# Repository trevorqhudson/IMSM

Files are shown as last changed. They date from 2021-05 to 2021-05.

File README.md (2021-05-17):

# IMSM
integrated multi-sensor module (IMSM) for transducing flow dynamics in hydrocephalic shunts

This repo contains firmware + schematics for a portable datalogger designed for an prototype polymer sensor device.

### Features: ###
* IMSM thermal flow sensor, bubble pressure sensor, and substrate/electrode integrity sensors using AD5933 LCR IC
* Low-side current sensing thru flow sensor heater 
* Sensirion LD20 flow sensor (I2C)
* EIS/CV sweeps addressable to any of 4 measurement electrode pairs + electrolysis electrodes
* Extends frequency range of AD5933 both low and high w/ external clock (code incomplete, but tapeout done)
* Completely autonomous data collection - designed for clinician use, not for researchers only
* Low-power + sleep mode extends battery life

[Meng Lab research page](https://biomems.usc.edu/ "easter egg text")

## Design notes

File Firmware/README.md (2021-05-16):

# Readme
Arduino code to interface AD5933 impedance analyzer and Teensy 3.2 microcontroller.
Used for flow and pressure sensing in platinum/Parylene C thin-film device.

Features:
* IMSM thermal flow sensor, bubble pressure sensor, and substrate/electrode integrity sensors using AD5933 LCR IC
* Low-side current sensing thru flow sensor heater 
* Sensirion LD20 flow sensor (I2C)
* EIS/CV sweeps addressable to any of 4 measurement electrode pairs + electrolysis electrodes
* Extends frequency range of AD5933 both low and high w/ external clock (code incomplete, but tapeout done)
* Completely autonomous data collection - designed for clinician use, not for engineers
* Low-power + sleep mode extends battery life

### Libraries ###
* Wire.h
* SD.h
* SPI.h
* math.h
* Time.h
* TimeLib.h
* Snooze.h
* SnoozeBlock.h

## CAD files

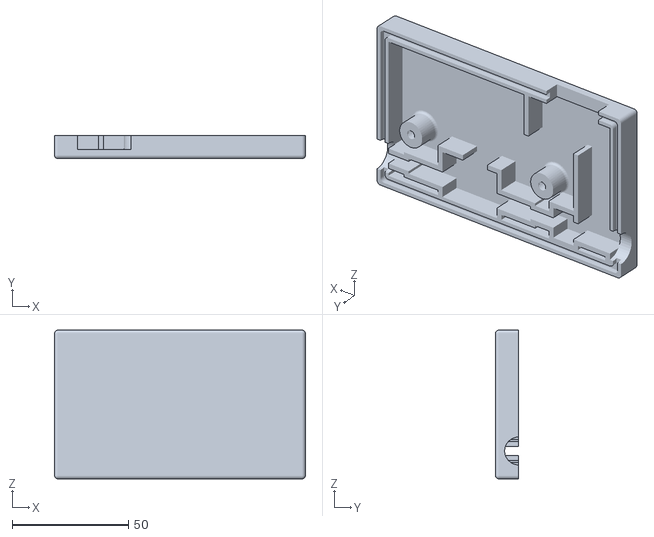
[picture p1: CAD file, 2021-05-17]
CAD/box bottom v2.STL
108.0 x 10.0 x 64.0

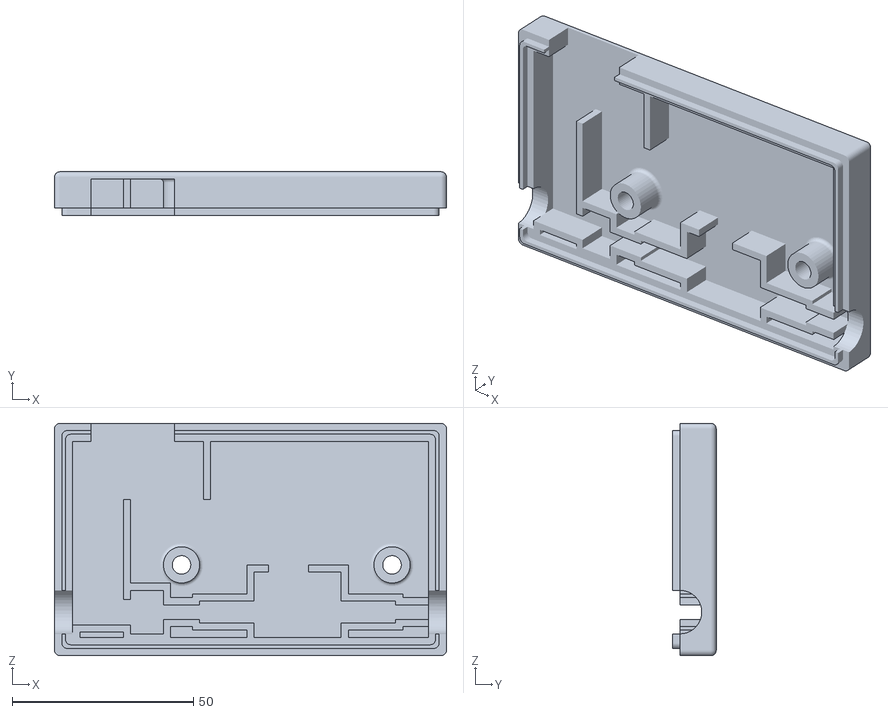
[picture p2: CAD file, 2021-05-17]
CAD/box top v2.STL
108.0 x 12.0 x 64.0

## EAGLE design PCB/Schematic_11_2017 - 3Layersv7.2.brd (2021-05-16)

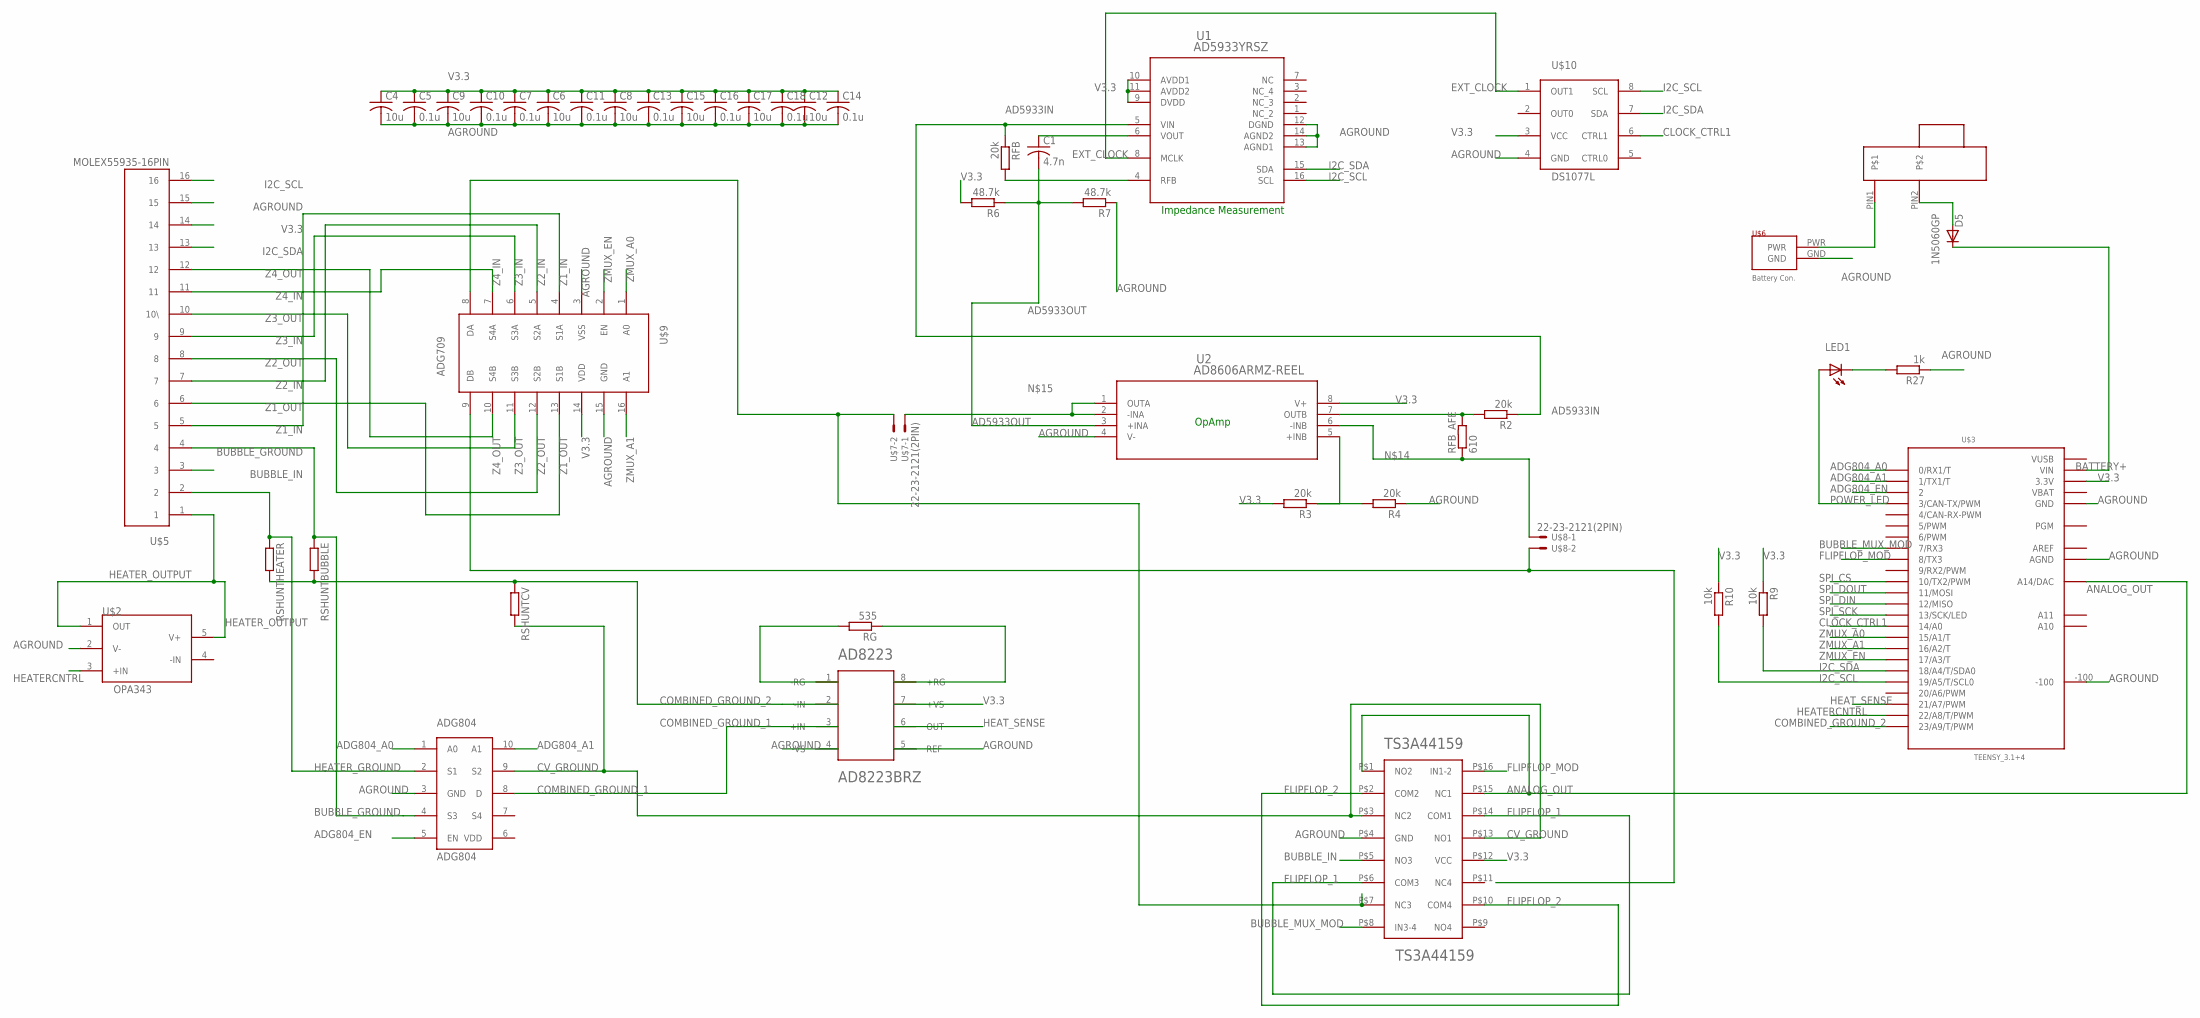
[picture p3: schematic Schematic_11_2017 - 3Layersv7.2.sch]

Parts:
ADG804: ADG804; MSOP10
C1: 4.7n; C1206
C4, C6, C8, C9, C12, C15, C17: 10u; C1206
C5, C7, C10, C11, C13, C14, C16, C18: 0.1u; C1206
D5: 1N5060GP; DO15-12
LED1: LED_ELD260; LED_LD260
R2, R3, R4: 20k; R1206
R6, R7: 48.7k; R1206
R9, R10: 10k; R1206
R27: 1k; R1206
RFB: 20k; R1206
RFB_AFE: 610; R1206
RG: 535; R1206
RSHUNTBUBBLE: RR1206; R1206
RSHUNTCV: RR1206; R1206
RSHUNTHEATER: RR1206; R1206
TS3A44159: TS3A44159; TSSOP16
U1: AD5933YRSZ; RS_16
U2: AD8606ARMZ-REEL; RM_8
U$1: AD8223BRZ; R-8
U$2: OPA343; SOT95P280X145-5N
U$3: TEENSY_3.1+4
U$4: C&KSWITCH; 2POS_SWITCH
U$5: MOLEX55935-16PIN
U$6: PH_2PIN; JST_PH_2PIN
U$7, U$8: 22-23-2121(2PIN)
U$9: ADG709; TSSOP16
U$10: DS1077L; SO08

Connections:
AD5933IN: R2.1, RFB.1, U1.5 (VIN)
AD5933OUT: C1.2, R6.1, R7.2, U2.3 (+INA)
ADG804_A0: ADG804.1 (A0), U$3.0 (0/RX1/T)
ADG804_A1: ADG804.10 (A1), U$3.1 (1/TX1/T)
ADG804_EN: ADG804.5 (EN), U$3.2
AGROUND: ADG804.3 (GND), C4.2, C5.2, C6.2, C7.2, C8.2, C9.2, C10.2, C11.2, C12.2, C13.2, C14.2, C15.2, C16.2, C17.2, C18.2, R4.1, R7.1, R27.1, TS3A44159.P$4 (GND), U1.12 (DGND), U1.13 (AGND1), U1.14 (AGND2), U2.4 (V-), U$1.4 (-VS), U$1.5 (REF), U$2.2 (V-), U$3.-100, U$3.AGND, U$3.GND1 (GND), U$5.15, U$6.GND, U$9.3 (VSS), U$9.15 (GND), U$10.4 (GND)
ANALOG_OUT: TS3A44159.P$1 (NO2), TS3A44159.P$15 (NC1), U$3.A14 (A14/DAC)
AREF: U$3.AREF
BATTERY+: D5.C, U$3.VIN
BUBBLE_GROUND: ADG804.4 (S3), RSHUNTBUBBLE.1, U$5.4
BUBBLE_IN: TS3A44159.P$5 (NO3), U$5.3
BUBBLE_MUX_MOD: TS3A44159.P$8 (IN3-4), U$3.7 (7/RX3)
CLOCK_CTRL1: U$3.14/A0, U$10.6 (CTRL1)
COMBINED_GROUND_1: ADG804.8 (D), U$1.3 (+IN)
COMBINED_GROUND_2: RSHUNTBUBBLE.2, RSHUNTCV.1, RSHUNTHEATER.2, U$1.2 (-IN), U$3.23/A9 (23/A9/T/PWM)
CV_GROUND: ADG804.9 (S2), RSHUNTCV.2, TS3A44159.P$3 (NC2), TS3A44159.P$13 (NO1)
EXT_CLOCK: U1.8 (MCLK), U$10.1 (OUT1)
FLIPFLOP_1: TS3A44159.P$6 (COM3), TS3A44159.P$14 (COM1)
FLIPFLOP_2: TS3A44159.P$2 (COM2), TS3A44159.P$10 (COM4)
FLIPFLOP_MOD: TS3A44159.P$16 (IN1-2), U$3.8 (8/TX3)
HEATERCNTRL: U$2.3 (+IN), U$3.22/A8 (22/A8/T/PWM)
HEATER_GROUND: ADG804.2 (S1), RSHUNTHEATER.1, U$5.2
HEATER_OUTPUT: U$2.1 (OUT), U$2.5 (V+), U$5.1
HEAT_SENSE: U$1.6 (OUT), U$3.21/A7 (21/A7/PWM)
I2C_SCL: R10.2, U1.16 (SCL), U$3.19/A5 (19/A5/T/SCL0), U$5.16, U$10.8 (SCL)
I2C_SDA: R9.2, U1.15 (SDA), U$3.18/A4 (18/A4/T/SDA0), U$5.13, U$10.7 (SDA)
unnamed: U$4.PIN1, U$6.PWR
unnamed: D5.A, U$4.PIN2
unnamed: RFB.2, U1.4 (RFB)
unnamed: LED1.K (C), R27.2
unnamed: C1.1, U1.6 (VOUT)
unnamed: R2.2, RFB_AFE.2, U2.7 (OUTB)
unnamed: R3.1, R4.2, U2.5 (+INB)
unnamed: RFB_AFE.1, U2.6 (-INB), U$8.1
unnamed: U2.1 (OUTA), U2.2 (-INA), U$7.1
unnamed: RG.2, U$1.1 (-RG)
unnamed: RG.1, U$1.8 (+RG)
POWER_LED: LED1.A, U$3.3 (3/CAN-TX/PWM)
SIGNAL+: TS3A44159.P$7 (NC3), U$7.2, U$9.8 (DA)
SIGNAL-: U$8.2, U$9.9 (DB)
SPI_CS: U$3.10 (10/TX2/PWM)
SPI_DIN: U$3.12 (12/MISO)
SPI_DOUT: U$3.11 (11/MOSI)
SPI_SCK: U$3.13 (13/SCK/LED)
V3.3: C4.1, C5.1, C6.1, C7.1, C8.1, C9.1, C10.1, C11.1, C12.1, C13.1, C14.1, C15.1, C16.1, C17.1, C18.1, R3.2, R6.2, R9.1, R10.1, TS3A44159.P$12 (VCC), U1.9 (DVDD), U1.10 (AVDD1), U1.11 (AVDD2), U2.8 (V+), U$1.7 (+VS), U$3.3.3V, U$3.3.3V1 (3.3V), U$5.14, U$9.14 (VDD), U$10.3 (VCC)
VBAT: U$3.VBAT
VUSB: U$3.VUSB
Z1_IN: U$5.5, U$9.4 (S1A)
Z1_OUT: U$5.6, U$9.13 (S1B)
Z2_IN: U$5.7, U$9.5 (S2A)
Z2_OUT: U$5.8, U$9.12 (S2B)
Z3_IN: U$5.9, U$9.6 (S3A)
Z3_OUT: U$5.10 (10\), U$9.11 (S3B)
Z4_IN: U$5.11, U$9.7 (S4A)
Z4_OUT: U$5.12, U$9.10 (S4B)
ZMUX_A0: U$3.15/A1 (15/A1/T), U$9.1 (A0)
ZMUX_A1: U$3.16/A2 (16/A2/T), U$9.16 (A1)
ZMUX_EN: U$3.17/A3 (17/A3/T), U$9.2 (EN)

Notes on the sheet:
Impedance Measurement
OpAmp

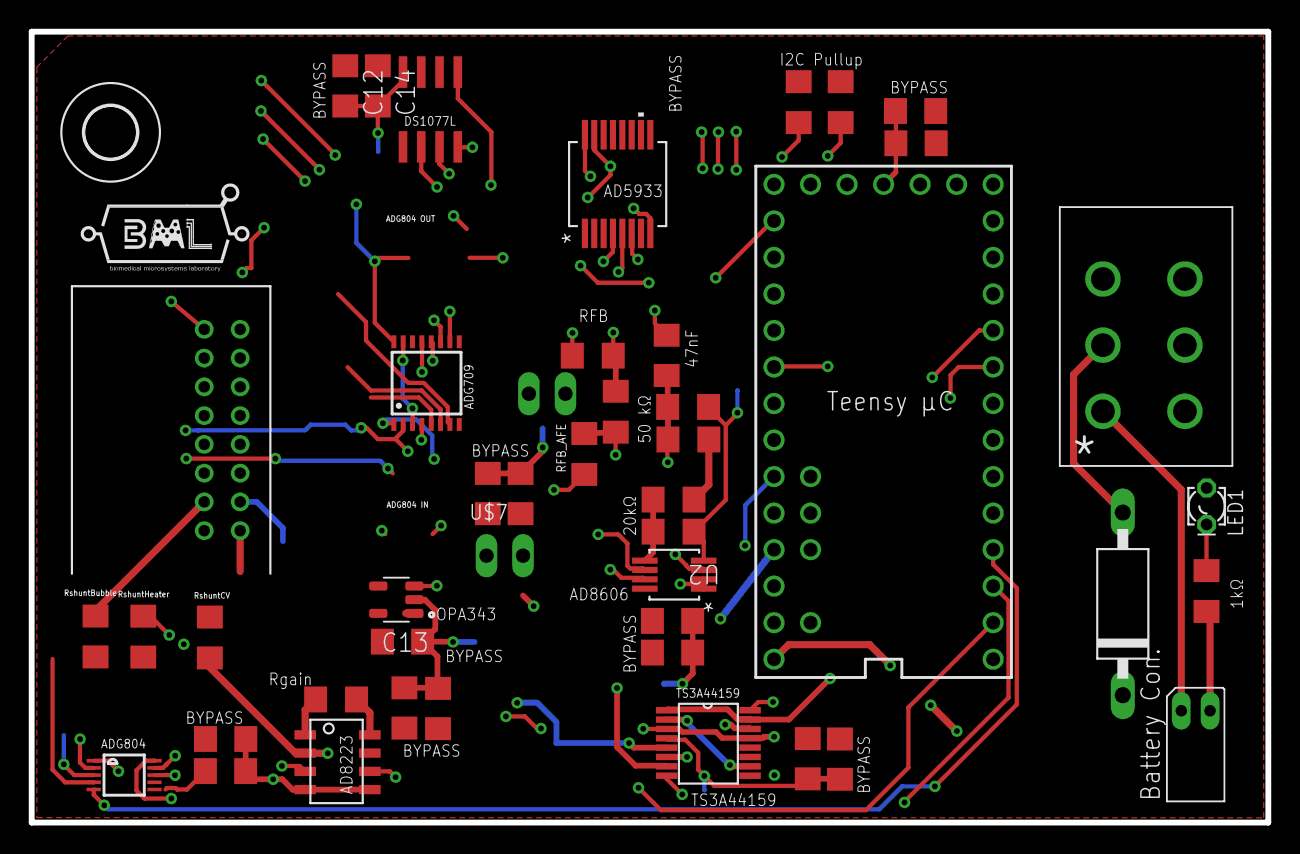
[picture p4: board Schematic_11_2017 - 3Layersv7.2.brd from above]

Board: 4 copper layers, 86.0 x 55.0 mm, 47 parts (0 on the bottom side), 51 nets.

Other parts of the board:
H1: MOUNT-HOLE3.6; 3,6

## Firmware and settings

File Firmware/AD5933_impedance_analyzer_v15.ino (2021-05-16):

// changelog
// 5_22 - 6_6: gather user inputs as global variables, add time_comments option, eliminate phase flowchart for simple atan2 output, add sweep option, change PGA gain to x5,
//             comment out SD pins reset at start of setup()
// 6_7: reset 'time_now' in flow() before calling freqfunction() such that sampling rate is more predictable and consistent
// 6_9: slightly changed string definition in freqfunction(), added 'flow_timer' input to freqfunction(), moved pinMode declarations inside of flow(), changed all outputs pins to
//      digital - research how grounding a microcontroller works, is it standard practice to add pulldown resistors
// 6_22:snooze library, heater_on to user-controllable vars, set unused I/O pins to output
// 6_23:cleaning up sweep operations
// 6_26:snooze lib readded, manually code in sweep
// 6_27:finished manually coding in sweep, set real_ and imag_read to record on SD
// 6_28:start removing features until we find problem
// 7_26:save program parameters in SD write header
// 8_3: snocontinuing with saving parameters in SD write header, added cut-off check for fluidic short
// 8_4: add pressure sensing code
// 8_9: change LED to constantly on, add phase constants for patency sweep
// 8_10:change flow programming to make AD5933 calls smoother
// 9_6: add 'operand' variable to ease user changes to signal type, add sig figs to impedance displaygain
// 11_21: this version contains voltage measurement apparatus on analog read pins, in flow function
// v11.99: commented out all "Serial" references to try to save power. this should be the only change from v11.98
// v12: add sweepflag=o before all naked freqfunction calls, and follow by turning off AD5933 - otherwise, startup register sets won't happen
// v12.02: sent to CHLA on 3.27 - rename this version to change parameters
// v12.04: added bubble generation voltage
// v12.05: combining Priya's code for higher frequency measurement. removed delay
// v12.06: protocol for Alex
// v13:    rewriting all for PCB v2: temp sensing, LD20, portable CV, pressure ramp [switching architecture]
// v14:    new board update. ADG709 mux replaces CD4052 mux. new pin layouts. added DS1077L external crystal. changed low-side current sensing circuit.
// v14.2:  add PGA gain variation, 1x on exposed IDE and 5x on flow and covered IDE. covered IDE is still out of range here
// v14.3:  add EIS distinct function

#include <Wire.h>
#include <SD.h>
#include <SPI.h>
#include <math.h>
#include <Time.h>
#include <TimeLib.h>
#include <Snooze.h>
#include <SnoozeBlock.h>

//snooze
SnoozeAlarm alarm;
SnoozeBlock config1(alarm);


//user-controllable vars, in no particular order
const uint32_t heat_time = 10000;  //time heater is on in msecs (flow)
const uint32_t warmup_time = 10000;
const uint32_t cooldown_time = 60000;
const uint32_t total_time = heat_time + cooldown_time + warmup_time;
const int NC_time = 10000;  //time nuc core electrodes are active in msecs (pressure)l
//gain factors calibrated for a 610 gain resistor for Z_mux
const float gain_factor_1x = 5.9788E6;  //this could be calculated w/ auto calibration step (freqfunction)
const float gain_factor_intercept_1x = -42.82;
const float gain_factor_5x = 3.0360E6;  //this could be calculated w/ auto calibration step (freqfunction)
const float gain_factor_intercept_5x = -397.23;
const boolean time_comments = false;
const int sense_resolution = 200; // msecs between ad5933 calls
boolean heater_on = true;
const int sleep_hours = 0;
const int sleep_mins = 55; //measurement cycle as is takes 04:05 [m:s] to complete, so 55 mins, 55 secs = 1 start per hour
const int sleep_secs = 55;
boolean CV_direction = true; //true = positive voltage defined as transmit electrodes, false = positive voltage through return electrodes

//deeper user vars
//  uint32_t act_code1 = 0xB0;
//  uint32_t act_code2 = 0x10;
//  uint32_t act_code3 = 0x20;
uint8_t operand = B0001;  //control interrogation voltage and PGA gain; see AD5933 datasheet [0=5x, 1=1x]
const int settling_time = 300;

//freq sweep vars
const int num_increm = 17;  //number of freq increments. if you change this, change phase offset array in freqfunction()
unsigned long start_freq;
const unsigned long delta_freq = 5000;
int sweep_index = 0;  //0 is start frequency, 1 is start + delta frequency, etc
bool sweepflag = 0; //0 is first sweep, 1 is mid-sweep,  controls activating/powering down AD5933
unsigned long AD5933_freq = 16000000; //16 MHz internal oscillator

//global vars
const int dtime = 10;  //delay between I2C operations, in usecs
const int CS = 4;  //pin select for CS
const float pi = 3.14159265;
boolean sweep_on = 0; //is  your measurement a frequency sweep or a single frequency?
const int AD5933ADDR = 0x0D;
uint16_t measure_number = 0;
int heat_voltage; //heater voltage sense
const float V_power = 3300; //[mB], PCB positive supply voltage
const float a_voltage_max = 4095; //12 bit resolution
const int DS1077LADDR = B1011000;

//sensirion LD20 vars
const int LD20_address = 8;
int ret;
float calibration_factor = 0.9; //20(mL/hr)^-1 => 1.2(uL/min)^-1; should be around 1.2, but is diff for every sensor
uint16_t sensor_flow_value;
int16_t signed_flow_value;
float scaled_flow_value;
byte sensor_flow_crc;
uint16_t sensor_temp_value;
byte sensor_temp_crc;
uint16_t aux_value;
byte aux_crc;

//pin assignments
const int ADG804_A0 = 0;
const int ADG804_A1 = 1;
const int ADG804_EN = 2;

const int LED = 3;

const int bubblemux_mod = 7; //mux between 4 signal electrode pairs (LOW) OR bubble input (HIGH)
const int flipflop_mod = 8; //flipflop mux between analog out as ch.1 and heater grond as ch.2 (LOW), or heater ground as ch.1 and analog out as ch.2 (HIGH)

const int CLOCK_CTRL1 = 14;
const int ZMUX_A0 = 15;
const int ZMUX_A1 = 16;
const int ZMUX_EN = 17;

const int heat_sense = 21;
const int heatercntrl = 22;
const int ground = 23;
const int analog_out = A14;

int myregister = 0;
int myregisterval = 0;

int measurement_index;  //tracks number of ad5933 calls

int global_imp_mag;


time_t getTeensy3Time() {
  return Teensy3Clock.get();
}


void setup() {
  Wire.begin();
  Serial.begin(9600);

  //  Serial.println("take3");

  //snooze stuff
  alarm.setRtcTimer(sleep_hours, sleep_mins, sleep_secs);

  //prepare analog output pin
  analogWriteResolution(12);
  analogWrite(analog_out, 0);

  //initialize SD card and make a file
  if (!SD.begin(CS)) {
    Serial.println("Card failed to read");
    return;
  }
  Serial.println("Card initialized");

  setSyncProvider(getTeensy3Time);

  //ground ground pin
  pinMode(ground, OUTPUT);
  digitalWrite(ground, LOW);

  //set unused I/O pins to OUTPUT to save power
  pinMode(0, OUTPUT); pinMode(1, OUTPUT); pinMode(2, OUTPUT); pinMode(5, OUTPUT); pinMode(6, OUTPUT);
  pinMode(10, OUTPUT); pinMode(11, OUTPUT); pinMode(12, OUTPUT); pinMode(13, OUTPUT); //pinMode(17, OUTPUT);

  //  Serial.end(); // shut off USB

  pinMode(LED, OUTPUT);      //turn on LED all the time
  digitalWrite(LED, HIGH);

  // Set all pinModes here for speed - none should change during program

  //talk to mux
  pinMode(ZMUX_A0, OUTPUT);  //corresponds to mux logic A
  pinMode(ZMUX_A1, OUTPUT);  //logic B
  pinMode(ZMUX_EN, OUTPUT);

  pinMode(heatercntrl, OUTPUT);

  pinMode(bubblemux_mod, OUTPUT);
  pinMode(flipflop_mod, OUTPUT);

  pinMode(heat_sense, INPUT);

  pinMode(CLOCK_CTRL1, OUTPUT);

  //default + safe switching mode is: flipflop=unflipped, bubble mux=bubble circuit(to isolate signal lines), R_shunt=low R
  digitalWrite(bubblemux_mod, HIGH);
  digitalWrite(flipflop_mod, LOW);

  digitalWrite(ADG804_EN, HIGH); //default open shunt resistor mux

  digitalWrite(CLOCK_CTRL1, HIGH); //default power down DS1077L

  delay(3000);  //time to write new program
}

void loop() {
  main1();
  measure_number++;

  delay(2000);  //don't remove this or snooze will crash

  Snooze.deepSleep(config1);
}



/////////////////////////////////////////////////////////////////////////////////////////////////////////////////////////////////////////////////////////////////////////////////

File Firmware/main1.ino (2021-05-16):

void main1() {
  writeSD("");
  writeSD("");
  writeSD("-------------------------------------------------");
  writeSD("BioFLEX_Firmware_v9.0");
  writeSD("AD5933_Interface Software_for_BioFLEX");
  writeSD("TH-Biomedical_Microsystems_Lab (Meng_Lab)");
  writeSD(String("Code_Version") + ": " + String("v13") + " " + String("heater_on") + ": " + String(heater_on) + " " + String("sleep_mins") + ": " + String(60 * sleep_hours + sleep_mins) + " " + String("sleep_secs") + " " + String(sleep_secs));
  writeSD(String("operand_code") + ": " + String(operand));
  //    writeSD(String("act_code1") + ": " + String(act_code1) + " " + String("act_code2") + ": " + String(act_code2) + " " + String("act_code3") + ": " + String(act_code3));
  writeSD(String("Measurement_Number") + ": " + String(measure_number) + " " + String("settling_time") + ": " + String(settling_time));
  writeSD(String("warmup_time") + ": " + String(warmup_time) + " " + String("heat_time") + ": " + String(heat_time) + " " + String("cooldown_time") + ": " + String(cooldown_time));
  writeSD(String(hour()) + ":" + String(minute()) + ":" + String(second()));
  writeSD(String(month()) + "/" + String(day()) + "/" + String(year()));
  writeSD("");

  measurement_index = 0;  //tracks number of ad5933 calls

  //flow1 (1)
  digitalWrite(ZMUX_A0, LOW);
  digitalWrite(ZMUX_A1, LOW);
  digitalWrite(ZMUX_EN, HIGH);
  writeSD("flow_1"); Serial.println("flow_1");
  sweep_on = false;
  start_freq = 50000;
  operand = B0001;

  for (int iii = 0; iii < 3; iii++) {
    flow();
    delay(1000);
  }


  //pressure (2)
  digitalWrite(ZMUX_A0, HIGH);
  digitalWrite(ZMUX_A1, LOW);
  writeSD("Pressure Sense"); Serial.println("Pressure Sense");


  operand = B0000;  //PGA gain = 5x
  sweep_on = true;
  start_freq = 5000;
  for (sweep_index = 0; sweep_index < (num_increm + 1); sweep_index++) {
    sweepflag = 0;
    freqfunction(millis());
    Serial.println(start_freq); Serial.println(global_imp_mag);
    wirewriteloop(0x80, 0xA0 | operand);
    start_freq += delta_freq;
  }


  //covered IDE (3)
  digitalWrite(ZMUX_A0, LOW);
  digitalWrite(ZMUX_A1, HIGH);
  writeSD("Covered IDE"); Serial.println("Covered IDE");


  operand = B0000;  //PGA gain = 5x
  sweep_on = true;
  start_freq = 5000;
  for (sweep_index = 0; sweep_index < (num_increm + 1); sweep_index++) {
    sweepflag = 0;
    freqfunction(millis());
    Serial.println(start_freq); Serial.println(global_imp_mag);
    wirewriteloop(0x80, 0xA0 | operand);
    start_freq += delta_freq;
  }

  //exposed IDE (4)
  digitalWrite(ZMUX_A0, HIGH);
  digitalWrite(ZMUX_A1, HIGH);
  writeSD("Exposed IDE"); Serial.println("Exposed IDE");

  operand = B0001; //set PGA gain to 1x
  sweep_on = true;
  start_freq = 5000;
  for (sweep_index = 0; sweep_index < (num_increm + 1); sweep_index++) {
    sweepflag = 0;
    freqfunction(millis());
    Serial.println(start_freq); Serial.println(global_imp_mag);
    wirewriteloop(0x80, 0xA0 | operand);
    start_freq += delta_freq;
  }


  //  digitalWrite(LED, LOW);
  writeSD("Meas_complete");
  //Serial.println("Meas_complete");
  digitalWrite(ZMUX_EN, LOW);
}
